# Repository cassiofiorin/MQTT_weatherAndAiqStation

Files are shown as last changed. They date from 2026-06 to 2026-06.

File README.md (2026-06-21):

# MQTT_weatherAndAiqStation
 
Retomada do projeto.

Inicialmente o projeto apenas imprimia as informações no display e via porta serial. A ideia seria armazenar os dados em banco de dados para consulta e histórico.

Atualmente houve uma mudança no segundo ponto, as informações não serão mais salvas em banco de dados, mas sim enviadas o Home Assistant através do protocolo MQTT.

Quanto ao barômetro, também foram criados alertas com base neste sensor, a ideia é alimentar o Home Assistant, que então envia alertas via Telegram sobre mudanças repentinas do clima.

Outra adição importante foi a inclusão do sensor SPS30 da Sensirion, que mede a densisdade de particulas supensas no ar e o tamanho delas. Indicando o nível de poluíção ambiental, assim como suas consequências para a respiração, com índice de qualidade do ar.

Também há arquivos STEP das caixas de cada sensor, esses arquivos são de modelagem próprios para o projeto, realizados conforme medidas de cada sensor, visando otimização do fluxo de ar e para comportar todos os componentes de maneira segura.

O código e comentários foram reorganizados utilizando a Qwen IA.

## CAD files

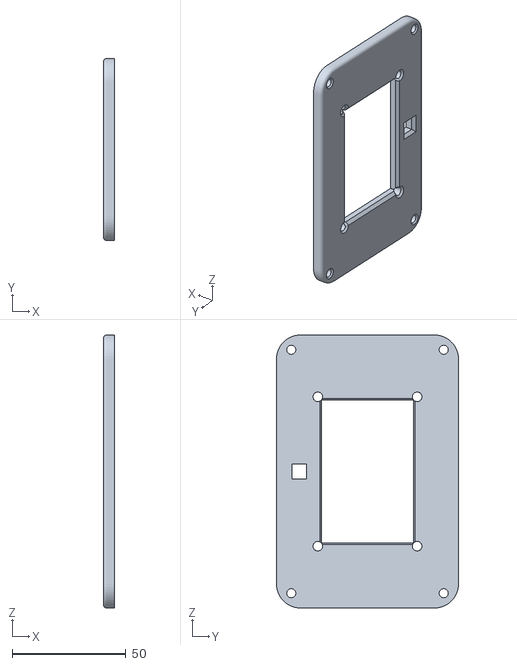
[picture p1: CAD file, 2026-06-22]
DisplayNode/Display Node - Top.stl
5.00 x 80.0 x 120.0

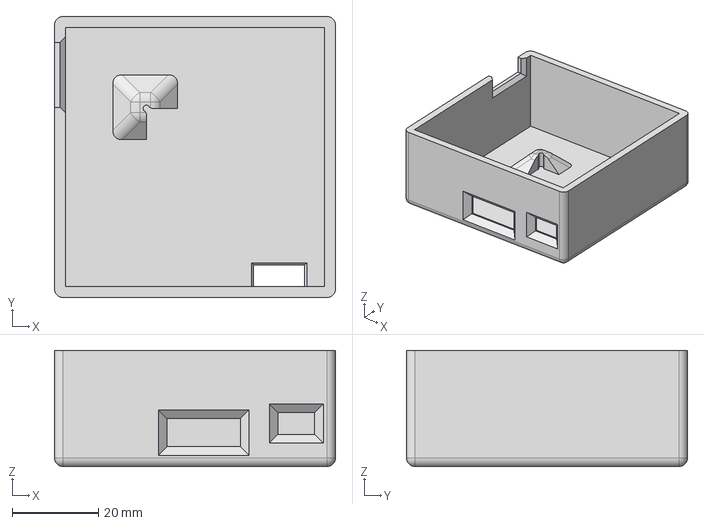
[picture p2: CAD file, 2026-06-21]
SPS30Node/Caixa SPS30.step
65.0 x 65.0 x 26.8 mm

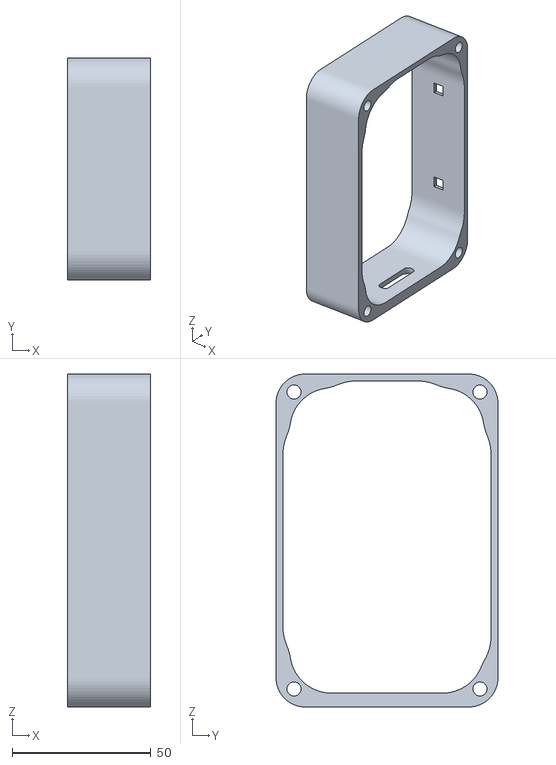
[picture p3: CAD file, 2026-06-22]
DisplayNode/Display Node - Walls.stl
30.0 x 80.0 x 120.0

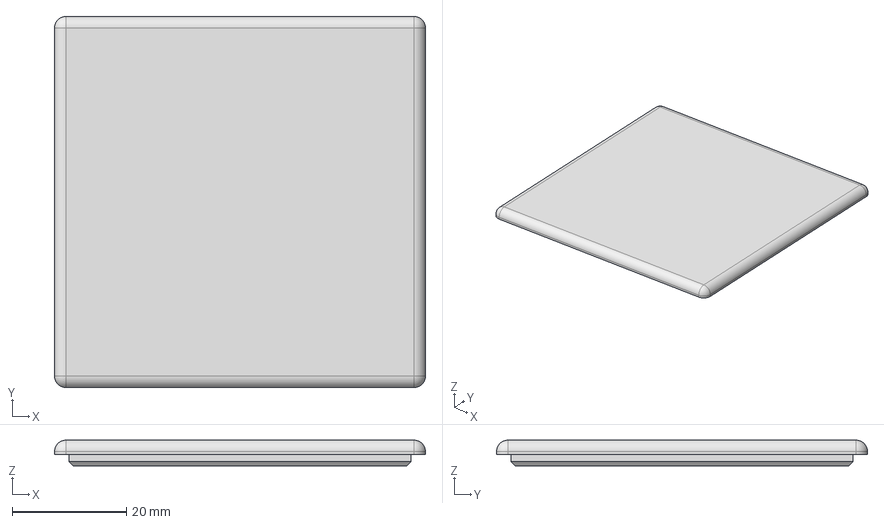
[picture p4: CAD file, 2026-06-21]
SPS30Node/Tampa SPS30.step
65.0 x 65.0 x 4.50 mm

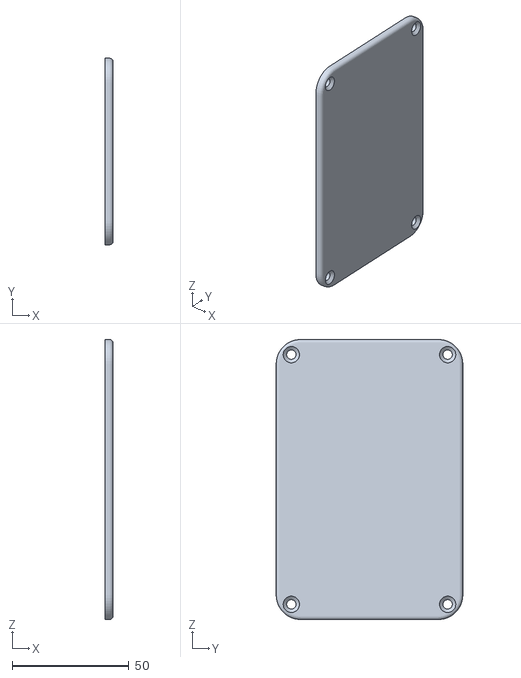
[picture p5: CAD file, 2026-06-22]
DisplayNode/Display Node - Back.stl
3.50 x 80.0 x 120.0

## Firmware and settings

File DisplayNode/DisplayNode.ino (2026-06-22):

/**
 * @file main.cpp
 * @brief Estação Barométrica Modular ESP32-S3
 * @description Arquitetura baseada em funções independentes para fácil manutenção.
 */

#include <WiFi.h>
#include <PubSubClient.h>
#include <Wire.h>
#include <RTClib.h>
#include <time.h>
#include <Adafruit_Sensor.h>
#include <Adafruit_BMP280.h>
#include <Adafruit_GFX.h>
#include <Adafruit_SSD1306.h>

// =============================================================================
// CONFIGURAÇÕES GERAIS (Constants & Structs)
// =============================================================================

struct Config {
  const char* ssid = "wifiNetwork";
  const char* password = "wifiPassword";
  const char* mqtt_server = "192.168.0.0";
  const int mqtt_port = 1883;
  const char* mqtt_user = "mqttUser";
  const char* mqtt_pass = "mqttPassword";
  
  const int pinI2C_SDA = 8;
  const int pinI2C_SCL = 9;
  const int pinButton = 4;
  
  const int screenW = 128;
  const int screenH = 64;
  const int oledReset = -1;
  const int displayAddr = 0x3C;
  
  const unsigned long intervalBarometer = 300000;   // 5 minutos (reduzido de 15min para 5min)
  const unsigned long intervalHourlyPublish = 3600000; 
  const unsigned long intervalWifiCheck = 30000;    
  const unsigned long durationAlertInit = 120000;   
  const unsigned long durationAlertDisplay = 1800000; 
  const unsigned long durationButtonWake = 30000;   
  const unsigned long debounceDelay = 50;
  
  // Calibração do sensor de temperatura (offset em °C)
  const float tempOffset = -1.0;  // Ajuste fino: -1.0 para compensar leitura 1°C acima
};

const Config cfg;

struct AlertThresholds {
  const float diff15 = 3.0;
  const float diff60 = 4.0;
  const float diff120 = 2.0;
};

const AlertThresholds thresholds;

// =============================================================================
// VARIÁVEIS GLOBAIS DE ESTADO (Compartilhadas entre módulos)
// =============================================================================

// Hardware Objects
WiFiClient espClient;
PubSubClient client(espClient);
RTC_DS3231 rtc;
Adafruit_BMP280 bmp;
Adafruit_SSD1306 display(cfg.screenW, cfg.screenH, &Wire, cfg.oledReset);

// Estados dos Módulos
bool isRtcFound = false;
bool isBmpFound = false;
bool isWifiConnected = false;
bool isDisplayOn = true;

// Estado da Lógica de Negócio
bool initPhaseSent = false;
bool initPhaseCleared = false;
float pressureHistory[9] = {0};
float currentTemp = 0.0;
float currentPressure = 0.0;
String currentAlertMsg = "Clima estavel";

// Timers Globais
unsigned long timerBarometer = 0;
unsigned long timerHourly = 0;
unsigned long timerWifi = 0;
unsigned long timerAlertInit = 0;
unsigned long timerAlertStart = 0;
unsigned long timerButtonWake = 0;
unsigned long timerDebounce = 0;

// Estado do Botão
int btnState = HIGH;
int lastBtnState = HIGH;

// =============================================================================
// MÓDULO: UTILITÁRIOS
// =============================================================================

void utilLog(const String& label, const String& msg) {
  Serial.println("[" + label + "] " + msg);
}

bool utilIsValidTime(DateTime t) {
  return (t.hour() <= 23 && t.minute() <= 59 && t.second() <= 59 &&
          t.day() >= 1 && t.day() <= 31 &&
          t.month() >= 1 && t.month() <= 12 &&
          t.year() >= 2020 && t.year() <= 2100);
}

void utilSetDisplayBrightness(uint8_t brightness) {
  Wire.beginTransmission(cfg.displayAddr);
  Wire.write(0x80); Wire.write(0x81);
  Wire.write(0x80); Wire.write(brightness);
  Wire.endTransmission();
}

// =============================================================================
// MÓDULO: DISPLAY (OLED)
// =============================================================================

void setupDisplay() {
  if (!display.begin(SSD1306_SWITCHCAPVCC, cfg.displayAddr)) {
    utilLog("ERROR", "Display SSD1306 nao encontrado");
    return;
  }
  utilSetDisplayBrightness(191);
  display.clearDisplay();
  display.setTextSize(2);
  display.setTextColor(SSD1306_WHITE);
  display.setCursor(0, 20);
  display.println("Iniciando...");
  display.display();
  utilLog("INFO", "Display inicializado");
}

void loopDisplayPowerManagement(unsigned long now) {
  if (!isRtcFound) return;

  DateTime t = rtc.now();
  bool isNight = (t.hour() >= 20 || t.hour() < 8);
  
  int reading = digitalRead(cfg.pinButton);
  if (reading != lastBtnState) {
    timerDebounce = now;
  }

  if ((now - timerDebounce) > cfg.debounceDelay) {
    if (reading != btnState) {
      btnState = reading;
      if (btnState == LOW) {
        timerButtonWake = now;
        utilLog("BTN", "Pressionado");
        if (!isDisplayOn) {
          display.ssd1306_command(SSD1306_DISPLAYON);
          isDisplayOn = true;
        }
      }
    }
  }
  lastBtnState = reading;

  if (isNight) {
    if (isDisplayOn && (now - timerButtonWake > cfg.durationButtonWake)) {
      display.ssd1306_command(SSD1306_DISPLAYOFF);
      isDisplayOn = false;
      utilLog("DISPLAY", "Desligado (Modo noturno)");
    }
  } else {
    if (!isDisplayOn) {
      display.ssd1306_command(SSD1306_DISPLAYON);
      isDisplayOn = true;
      utilLog("DISPLAY", "Ligado (Modo diurno)");
    }
  }
}

void loopDisplayRender() {
  if (!isDisplayOn) return;

  display.clearDisplay();
  display.setTextColor(SSD1306_WHITE);
  
  // Data/Hora
  if (isRtcFound) {
    DateTime now = rtc.now();
    if (utilIsValidTime(now)) {
      display.setTextSize(1);
      display.setCursor(34, 0);
      display.printf("%02d/%02d/%04d", now.day(), now.month(), now.year());
      display.setTextSize(2);
      display.setCursor(16, 10);
      display.printf("%02d:%02d:%02d", now.hour(), now.minute(), now.second());
    } else {
      display.setTextSize(1);
      display.setCursor(0, 0);
      display.println("RTC dados invalidos");
    }
  } else {
    display.setTextSize(1);
    display.setCursor(0, 0);
    display.println("RTC nao encontrado");
  }
  
  // Sensores
  if (isBmpFound) {
    display.setTextSize(1);
    display.setCursor(28, 30);
    display.printf("Temp: %.1f C", currentTemp);
    display.setCursor(19, 42);
    display.printf("Press: %.1f hPa", currentPressure);
  }
  
  // Alerta
  display.setTextSize(1);
  display.setCursor(25, 56);
  String displayMsg = currentAlertMsg.length() > 18 ? currentAlertMsg.substring(0, 17) + "." : currentAlertMsg;
  display.print(displayMsg);
  
  display.display();
}

// =============================================================================
// MÓDULO: SENSORES (RTC e BMP280)
// =============================================================================

void setupSensors() {
  // RTC
  if (rtc.begin()) {
    isRtcFound = true;
    utilLog("INFO", "RTC DS3231 encontrado");
    if (!utilIsValidTime(rtc.now())) {
      utilLog("WARN", "RTC com data invalida");
    }
  } else {
    utilLog("ERROR", "RTC DS3231 nao encontrado");
  }

  // BMP280
  if (bmp.begin(0x76)) {
    isBmpFound = true;
    utilLog("INFO", "BMP280 encontrado");
    bmp.setSampling(Adafruit_BMP280::MODE_NORMAL,
                    Adafruit_BMP280::SAMPLING_X2,
                    Adafruit_BMP280::SAMPLING_X16,
                    Adafruit_BMP280::FILTER_X16,
                    Adafruit_BMP280::STANDBY_MS_500);
  } else {
    utilLog("ERROR", "BMP280 nao encontrado");
  }
}

void loopSensorReadings(unsigned long now) {
  if (!isBmpFound || (now - timerBarometer < cfg.intervalBarometer)) return;
  
  timerBarometer = now;
  
  // Leitura direta
  float newTemp = bmp.readTemperature() + cfg.tempOffset;  // Aplica calibração de temperatura
  float newPressure = bmp.readPressure() / 100.0F;
  
  utilLog("SENSOR", "Temp: " + String(newTemp, 1) + " C | Pressao: " + String(newPressure, 1) + " hPa");
  
  // Atualiza histórico (desloca valores antigos)
  for (int i = 8; i > 0; i--) {
    pressureHistory[i] = pressureHistory[i-1];
  }
  pressureHistory[0] = newPressure;
  
  // Atualiza variáveis globais APÓS salvar no histórico
  currentTemp = newTemp;
  currentPressure = newPressure;
  
  // Publica dados no MQTT imediatamente após leitura
  if (isWifiConnected && client.connected()) {
    char tempStr[10];
    char pressStr[10];
    dtostrf(currentTemp, 1, 1, tempStr);
    dtostrf(currentPressure, 1, 1, pressStr);
    
    networkPublish("casa/temperatura", tempStr);
    networkPublish("casa/pressao", pressStr);
    utilLog("MQTT", "Dados publicados: Temp=" + String(tempStr) + " Pressao=" + String(pressStr));
  }
}

void syncRTCIfNeeded() {
  if (!isRtcFound || !isWifiConnected) return;

  DateTime now = rtc.now();
  bool needsSync = (now.year() < 2026 || (now.year() == 2026 && now.month() < 6)) || !utilIsValidTime(now);
  
  if (needsSync) {
    utilLog("INFO", "Sincronizando RTC com NTP...");
    struct tm timeinfo;
    if (getLocalTime(&timeinfo)) {
      rtc.adjust(DateTime(timeinfo.tm_year + 1900, timeinfo.tm_mon + 1, timeinfo.tm_mday, 
                          timeinfo.tm_hour, timeinfo.tm_min, timeinfo.tm_sec));
      utilLog("INFO", "RTC atualizado via NTP");
    }
  }
}

// =============================================================================
// MÓDULO: REDE (WiFi e MQTT)
// =============================================================================

void setupNetwork() {
  utilLog("WIFI", "Conectando...");
  WiFi.disconnect();
  WiFi.begin(cfg.ssid, cfg.password);
  
  int tries = 0;
  while (WiFi.status() != WL_CONNECTED && tries < 60) {
    delay(500);
    Serial.print(".");
    tries++;
  }

  if (WiFi.status() == WL_CONNECTED) {
    isWifiConnected = true;
    utilLog("WIFI", "Conectado! IP: " + WiFi.localIP().toString());
    configTime(-10800, 0, "time.cloudflare.com");
    
    client.setServer(cfg.mqtt_server, cfg.mqtt_port);
    client.setKeepAlive(30);
    networkSendDiscoveryConfig();
  } else {
    isWifiConnected = false;
    utilLog("ERROR", "Falha na conexao WiFi");
  }
}

void loopNetworkMaintenance(unsigned long now) {
  if (now - timerWifi > cfg.intervalWifiCheck) {
    timerWifi = now;
    if (WiFi.status() != WL_CONNECTED) {
      utilLog("WARN", "WiFi desconectado. Reconectando...");
      isWifiConnected = false;
      setupNetwork(); // Reutiliza a lógica de conexão
      if (isWifiConnected && !client.connected()) {
        networkReconnectMQTT();
      }
    }
  }
  
  if (isWifiConnected && !client.connected()) {
    networkReconnectMQTT();
  }
  
  if (isWifiConnected) {
    client.loop();
  }
}

void networkReconnectMQTT() {
  String clientId = "ESP32_S3_Sensor_" + String((uint32_t)ESP.getEfuseMac(), HEX);
  if (client.connect(clientId.c_str(), cfg.mqtt_user, cfg.mqtt_pass)) {
    utilLog("MQTT", "Conectado");
    networkSendDiscoveryConfig();
  } else {
    utilLog("WARN", "Falha MQTT rc=" + String(client.state()));
    delay(5000);
  }
}

void networkSendDiscoveryConfig() {
  if (!isWifiConnected || !client.connected()) return;
  
  client.publish("homeassistant/sensor/esp32_ar_temp/config", 
    "{\"name\":\"Temperatura ESP\",\"state_topic\":\"casa/temperatura\",\"unit_of_measurement\":\"°C\",\"device_class\":\"temperature\",\"unique_id\":\"esp32_ar_temp\"}", true);
  client.publish("homeassistant/sensor/esp32_ar_pressao/config", 
    "{\"name\":\"Pressao ESP\",\"state_topic\":\"casa/pressao\",\"unit_of_measurement\":\"hPa\",\"device_class\":\"pressure\",\"unique_id\":\"esp32_ar_pressao\"}", true);
  client.publish("homeassistant/sensor/esp32_ar_alerta/config", 
    "{\"name\":\"Alerta Clima ESP\",\"state_topic\":\"casa/alerta_clima\",\"unique_id\":\"esp32_ar_alerta\"}", true);
}

void networkPublish(const char* topic, const char* payload) {
  if (isWifiConnected && client.connected()) {
    client.publish(topic, payload);
  }
}

// =============================================================================
// MÓDULO: LÓGICA DE ALERTAS E NEGÓCIO
// =============================================================================

void loopAlertLogicInitialization(unsigned long now) {
  // Fase Inicial (Iniciando -> Monitorando)
  if (isBmpFound && !initPhaseSent && isWifiConnected) {
    networkPublish("casa/alerta_clima", "Iniciando");
    delay(200);
    networkPublish("casa/alerta_clima", "Iniciando");
    utilLog("ALERT", "Fase inicial: Iniciando");
    
    initPhaseSent = true;
    timerAlertInit = now;
  }

  if (initPhaseSent && !initPhaseCleared && isWifiConnected && (now - timerAlertInit > cfg.durationAlertInit)) {
    networkPublish("casa/alerta_clima", "Monitorando");
    utilLog("ALERT", "Fase inicial: Monitorando");
    initPhaseCleared = true;
  }
}

void loopAlertLogicEvaluation() {
  // Só avalia se temos leituras válidas no histórico
  bool triggered = false;
  String msg = "";

  if (pressureHistory[0] > 0) {
    float diff = currentPressure - pressureHistory[0];
    if (diff <= -thresholds.diff15) {
      msg = "PIORA RAPIDA: Queda (" + String(diff, 1) + " hPa/15min)";
      triggered = true;
    } else if (diff >= thresholds.diff15) {
      msg = "MELHORA RAPIDA: Alta (" + String(diff, 1) + " hPa/15min)";
      triggered = true;
    }
  }

  if (!triggered && pressureHistory[3] > 0) {
    float diff = currentPressure - pressureHistory[3];
    if (diff <= -thresholds.diff60) {
      msg = "TENDENCIA FORTE PIORA: (" + String(diff, 1) + " hPa/1h)";
      triggered = true;
    } else if (diff >= thresholds.diff60) {
      msg = "TENDENCIA FORTE MELHORA: (" + String(diff, 1) + " hPa/1h)";
      triggered = true;
    }
  }

  if (!triggered && pressureHistory[7] > 0) {
    float diff = currentPressure - pressureHistory[7];
    if (diff <= -thresholds.diff120) {
      msg = "TENDENCIA MODERADA PIORA: (" + String(diff, 1) + " hPa/2h)";
      triggered = true;
    } else if (diff >= thresholds.diff120) {
      msg = "TENDENCIA MODERADA MELHORA: (" + String(diff, 1) + " hPa/2h)";
      triggered = true;
    }
  }

  if (triggered) {
    currentAlertMsg = msg;
    timerAlertStart = millis();
    utilLog("ALERT", msg);
    networkPublish("casa/alerta_clima", msg.c_str());
  }
}

void loopAlertLogicHourlyStatus(unsigned long now) {
  if (!isWifiConnected || !initPhaseCleared || (now - timerHourly < cfg.intervalHourlyPublish)) return;
  
  timerHourly = now;
  
  if (currentAlertMsg == "Clima estavel" || (now - timerAlertStart > cfg.durationAlertDisplay)) {
    networkPublish("casa/alerta_clima", "Sem alerta");
    utilLog("ALERT", "Status horario: Sem alerta");
    currentAlertMsg = "Sem alerta";
  }
}

void loopAlertLogicExpiration(unsigned long now) {
  if (currentAlertMsg != "Clima estavel" && currentAlertMsg != "Sem alerta") {
    if (now - timerAlertStart > cfg.durationAlertDisplay) {
      currentAlertMsg = "Clima estavel";
      utilLog("ALERT", "Alerta expirou no display");
    }
  }
}

// =============================================================================
// MAIN: SETUP E LOOP
// =============================================================================

void setup() {
  Serial.begin(115200);
  delay(2000);
  utilLog("SYS", "=== Inicializando Estacao Barometrica ===");

  Wire.begin(cfg.pinI2C_SDA, cfg.pinI2C_SCL, 400000);
  pinMode(cfg.pinButton, INPUT_PULLUP);

  // 1. Inicializa Display
  setupDisplay();

  // 2. Inicializa Sensores
  setupSensors();

  // 3. Inicializa Rede
  setupNetwork();

  // 4. Sync RTC (depende de Rede e Sensor)
  syncRTCIfNeeded();

  // Inicializa timers
  timerBarometer = millis() - cfg.intervalBarometer; // Permite leitura imediata
  timerHourly = millis();
  timerWifi = millis();
  
  utilLog("SYS", "=== Setup Concluido ===");
}

void loop() {
  unsigned long now = millis();

  // 1. Gerenciamento de Energia do Display (Botão/Horário)
  loopDisplayPowerManagement(now);

  // 2. Manutenção de Rede (Reconexão WiFi/MQTT)
  loopNetworkMaintenance(now);

  // 3. Lógica de Inicialização do Sistema (Mensagem "Iniciando")
  loopAlertLogicInitialization(now);

  // 4. Leitura de Sensores (A cada 15 min)
  bool sensorRead = false;
  if (isBmpFound && (now - timerBarometer >= cfg.intervalBarometer)) {
    loopSensorReadings(now);
    sensorRead = true;
  }

  // 5. Avaliação de Alertas (apenas quando há nova leitura de sensores)
  if (sensorRead) {
     loopAlertLogicEvaluation();
  }

  // 6. Publicação Horária de Status
  loopAlertLogicHourlyStatus(now);

  // 7. Expiração Visual de Alertas
  loopAlertLogicExpiration(now);

  // 8. Renderização do Display (Se ligado)
  loopDisplayRender();

  delay(10);
}

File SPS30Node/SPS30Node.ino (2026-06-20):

/**
 * @file main.cpp
 * @brief Nó de Qualidade do Ar (Sensirion SPS30)
 * @description Leitura de partículas, cálculo de AQI, limpeza automática e integração Home Assistant.
 */

#include <Arduino.h>
#include <WiFi.h>
#include <PubSubClient.h>
#include <Wire.h>
#include <SensirionI2cSps30.h>
#include <EEPROM.h>
#include <time.h>

// =============================================================================
// DEFINIÇÕES E CONSTANTES GLOBAIS
// =============================================================================

// Define NO_ERROR caso a biblioteca não o exponha globalmente neste contexto
#ifdef NO_ERROR
#undef NO_ERROR
#endif
#define NO_ERROR 0

struct Config {
  // Rede e MQTT
  const char* ssid = "wifiName";
  const char* password = "wifiPassword";
  const char* mqtt_server = "192.168.0.0";
  const int mqtt_port = 1883;
  const char* mqtt_user = "mqttUser";
  const char* mqtt_pass = "mtqqPassword";
  
  // NTP
  const char* ntpServer = "pool.ntp.org";
  const long gmtOffset_sec = -3 * 3600;
  const int daylightOffset_sec = 0;

  // Sensor e Limpeza
  const int eepromSize = 16;
  const int addrLastCleaning = 0;
  const unsigned long cleaningIntervalSec = 604800; // 1 semana
  
  // Timings
  const unsigned long intervalSerialStartup = 10000;
  const unsigned long intervalMqttPublish = 120000;   // 2 min
  const unsigned long timeStabilization = 60000;      // 1 min
};

const Config cfg;

// =============================================================================
// VARIÁVEIS GLOBAIS DE ESTADO
// =============================================================================

// Hardware Objects
WiFiClient espClient;
PubSubClient client(espClient);
SensirionI2cSps30 sensor;

// Estado do Sensor
uint16_t mc1p0 = 0, mc2p5 = 0, mc4p0 = 0, mc10p0 = 0;
uint16_t nc0p5 = 0, nc1p0 = 0, nc2p5 = 0, nc4p0 = 0, nc10p0 = 0;
uint16_t typicalParticleSize = 0;
bool isSensorDataValid = false;

// Estado da Qualidade do Ar
String airQualityStatus = "Calculando...";
uint16_t aqiNumeric = 0;
String lastCleaningDate = "Nunca";

// Estado do Sistema
bool isInitialPublishDone = false;
static char errorMessage[64];
static int16_t errorCode;

// Timers
unsigned long timerSerial = 0;
unsigned long timerMqtt = 0;

// =============================================================================
// MÓDULO: UTILITÁRIOS
// =============================================================================

void utilLog(const String& label, const String& msg) {
  Serial.println("[" + label + "] " + msg);
}

String utilGetDateTime() {
  struct tm timeinfo;
  if (!getLocalTime(&timeinfo)) return "Data indisponivel";
  char buffer[32];
  sprintf(buffer, "%02d/%02d/%04d %02d:%02d", 
          timeinfo.tm_mday, timeinfo.tm_mon + 1, timeinfo.tm_year + 1900, 
          timeinfo.tm_hour, timeinfo.tm_min);
  return String(buffer);
}

unsigned long utilGetTimestamp() {
  struct tm timeinfo;
  if (!getLocalTime(&timeinfo)) return 0;
  return (unsigned long)mktime(&timeinfo);
}

// =============================================================================
// MÓDULO: EEPROM (Persistência)
// =============================================================================

void setupEeprom() {
  EEPROM.begin(cfg.eepromSize);
  utilLog("EEPROM", "Inicializado (" + String(cfg.eepromSize) + " bytes)");
}

void eepromSaveCleaningTime(unsigned long timestamp) {
  EEPROM.put(cfg.addrLastCleaning, timestamp);
  EEPROM.commit();
  utilLog("EEPROM", "Timestamp de limpeza salvo");
}

unsigned long eepromGetLastCleaningTime() {
  unsigned long timestamp = 0;
  EEPROM.get(cfg.addrLastCleaning, timestamp);
  return timestamp;
}

// =============================================================================
// MÓDULO: SENSOR (SPS30)
// =============================================================================

void setupSensorHardware() {
  Wire.begin();
  sensor.begin(Wire, SPS30_I2C_ADDR_69);
  sensor.stopMeasurement();
  
  int8_t serialNumber[32] = {0};
  sensor.readSerialNumber(serialNumber, 32);
  utilLog("SENSOR", "SPS30 Iniciado. SN: " + String((const char*)serialNumber));
  
  sensor.startMeasurement(SPS30_OUTPUT_FORMAT_OUTPUT_FORMAT_UINT16);
  delay(100);
  utilLog("SENSOR", "Medicao iniciada");
}

void loopSensorReadings() {
  errorCode = sensor.readMeasurementValuesUint16(mc1p0, mc2p5, mc4p0, mc10p0,
                                                 nc0p5, nc1p0, nc2p5, nc4p0,
                                                 nc10p0, typicalParticleSize);
  
  if (errorCode != NO_ERROR) {
    errorToString(errorCode, errorMessage, sizeof errorMessage);
    utilLog("ERRO", "Leitura SPS30 falhou: " + String(errorMessage));
    isSensorDataValid = false;
    return;
  }
  
  isSensorDataValid = true;
}

void loopSensorMaintenance() {
  unsigned long lastCleaning = eepromGetLastCleaningTime();
  unsigned long currentTs = utilGetTimestamp();
  
  bool forceClean = (lastCleaning == 0);
  bool intervalReached = (currentTs > 0 && (currentTs - lastCleaning) >= cfg.cleaningIntervalSec);
  
  if (forceClean || intervalReached) {
    utilLog("MANUT", forceClean ? "Primeira operacao. Limpando..." : "Intervalo semanal atingido. Limpando...");
    
    // Iniciar limpeza
    errorCode = sensor.startFanCleaning();
    if (errorCode != NO_ERROR) {
      errorToString(errorCode, errorMessage, sizeof errorMessage);
      utilLog("ERRO", "Falha ao iniciar limpeza: " + String(errorMessage));
      return;
    }
    
    utilLog("MANUT", "Limpeza em andamento (10s)...");
    delay(10000);
    
    // Salvar novo timestamp
    unsigned long newTs = utilGetTimestamp();
    if (newTs > 0) {
      eepromSaveCleaningTime(newTs);
      lastCleaningDate = utilGetDateTime();
      utilLog("MANUT", "Limpeza concluida em: " + lastCleaningDate);
      
      // Publicar atualização imediata se MQTT estiver conectado
      if (client.connected()) {
        client.publish("casa/ar/sps30_ultima_limpeza", lastCleaningDate.c_str(), true);
      }
    }
  } else {
    // Apenas atualiza string para display/logs se não limpou agora
    if (lastCleaning > 0) {
      struct tm timeinfo;
      time_t lastTime = (time_t)lastCleaning;
      localtime_r(&lastTime, &timeinfo);
      char buffer[32];
      sprintf(buffer, "%02d/%02d/%04d %02d:%02d", 
              timeinfo.tm_mday, timeinfo.tm_mon + 1, timeinfo.tm_year + 1900, 
              timeinfo.tm_hour, timeinfo.tm_min);
      lastCleaningDate = String(buffer);
    }
  }
}

// =============================================================================
// MÓDULO: QUALIDADE DO AR (Lógica de Negócio)
// =============================================================================
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

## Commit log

2026-06-20 Remoção de secret
2026-06-20 Inclusão de informações no README
    Detalhamento do momento do projeto no README
2026-06-20 Fix initial sensor readings in Display Node
    - Modified DisplayNode.ino to initialize timerBarometer with negative interval value, enabling immediate sensor readings upon startup instead of waiting 15 minutes
    - Added .gitignore file to exclude build artifacts, dependencies, logs, environment files, editor configs, and OS-specific files from version control
    The primary fix addresses the issue of zero sensor values at startup by ensuring the BMP280 temperature and barometer readings occur immediately after initialization. The .gitignore improves project cleanliness.
    [DisplayNode.ino]
2026-06-20 Fix sensor reading logic and update gitignore
    - Modified .gitignore to add comprehensive ignore patterns for build artifacts, dependencies, logs, and temp files
    - Fixed sensor reading logic in DisplayNode.ino to ensure currentTemp and currentPressure are updated correctly after history buffer is populated
    - Added explicit boolean flag to control alert evaluation timing based on sensor readings
    - Ensured sensor readings occur every 15 minutes and alert logic runs immediately after new readings
    - Improved code structure in main loop to make sensor reading and alert evaluation dependency clearer
    [DisplayNode.ino]
2026-06-20 Fix sensor update and MQTT publishing issue
    - Modified DisplayNode.ino to ensure sensor readings trigger immediate MQTT publishing after updating global variables
    - Updated loopSensorReadings function to publish temperature and pressure data to MQTT topics casa/temperatura and casa/pressao immediately after each sensor read
    - Fixed timing issue where MQTT publishing was not occurring simultaneously with display updates
    - Ensured currentTemp and currentPressure global variables are updated before MQTT publication
    The changes resolve the reported issue where pressure updates were confirmed internally but not reflected on the display or published to MQTT by ensuring the publication occurs imme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
    [DisplayNode.ino]
2026-06-20 Fix pressure value formatting in display output
    - Updated DisplayNode/DisplayNode.ino to correct pressure display formatting from "%.0f hPa" to "%.1f hPa" for consistent decimal precision matching MQTT publishing format
    - Modified dtostrf call for pressure to use 1 decimal place instead of 0 when publishing to MQTT topics
    - Ensured display rendering and MQTT publishing use same precision for pressure values improving consistency
    [DisplayNode.ino]
2026-06-21 Arquivos STEP da caixa impressa em 3D
    Caixa simples, com saídas de ventilação espaço para um conector USB C
    [Caixa SPS30.step, Tampa SPS30.step]
2026-06-21 Update README.md
    Inclusão de informações sobre os arquivos 3D.
2026-06-22 Inclusão de arquivos STL (3D)
    Inclusão de arquivos em 3D para o nó da caixa.
    Ela suporta o ESP com uma placa perfurada usada para montagem da fiação dos sensores, tampa montagem do display e espaço para o botão e dois espaços no topo para circulação do ar.
    Há também espaço lateral para os USBs do ESP32 S3.
    [Display Node - Back.stl, Display Node - Top.stl, Display Node - Walls.stl]
2026-06-22 Add temperature offset calibration and update barometer interval
    -Key files changed:
    -DisplayNode/DisplayNode.ino Add tempOffset constant to Config struct and apply in sensor readings, reduce barometer interval from 15 to 5 minutes
    -.gitignore Update ignore patterns and add environment file rules
    The code now includes a configurable temperature offset for sensor calibration and increases the frequency of barometer readings. The gitignore file is updated for better project cleanliness.
